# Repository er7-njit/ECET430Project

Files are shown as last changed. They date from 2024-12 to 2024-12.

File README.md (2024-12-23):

# GPS Tracker Project
Eliyahu Richter and Ravyn John's ECET 430 Project

Our initial **Project Definition** is available [here](https://github.com/er7-njit/GPSTracker430/blob/main/Documentation/Initial%20Project%20Definition.pdf)

Our final **Project Definition** is available [here](https://github.com/er7-njit/GPSTracker430/blob/main/Documentation/Final%20Project%20Definition.pdf)

A summary of our **Component Decisions** is available [here](https://github.com/er7-njit/GPSTracker430/blob/main/Documentation/Design%20decision.pdf)

**Documentation** is available [here](https://github.com/er7-njit/GPSTracker430/blob/main/Documentation/Documentation.md)

The **Logbook** for the project's progress is [here](https://github.com/er7-njit/GPSTracker430/wiki/Logbook)

Our **Project Files** are [here](https://github.com/er7-njit/GPSTracker430/tree/main/PCB%20Design)

Most questions about our project can be answered by the [wiki](https://github.com/er7-njit/GPSTracker430/wiki)





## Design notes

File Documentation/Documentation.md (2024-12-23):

# User Documentation

**DISCLAIMER: The Pi Tracker is still in development, the steps outlined here are for setup in uses related to development ONLY. The Pi Tracker is not supported, or recommended for use in production environments**

### Table of Contents
1. Supported Hardware
2. Device Summary
3. Basic Setup and Operation
4. Troubleshooting steps

## Supported Hardware
**Microcontrollers**:
- Raspberry Pi Zero W\
\
**OS Support**:
- Pi OS Lite\
\
**GPS Support**:
- Adafruit Ultimate GPS\
\
**WWAN Module Support**:
- Sierra Wireless EM7455

## Device Summary
The Pi Tracker is a tracking device that utilizes an Adafruit GPS module and a Sierra EM7455 WWAN Module to wirelessly transmit its location to the cloud. Its base componentry is a Pi Zero W (Figure 1), Adafruit Ultimate GPS attached by USB (Figure 2), and Sierra EM7455 WWAN Interface (FIgure 3) attached via a miniPCIe to USB adapter. Both of these interfaces are attached to a USB hub, which is connected to the Pi. 

## Basic Setup and Operation
**Device Assembly**
###
Firstly, connect the GPS and WWAN Module to the USB Hub. Then, connect the USB hub to the inner USB OTG port of the Pi Zero. Finally, connect the Pi to USB power using the outside USB port. 
###
**Device Setup**
###
1. Using the [Raspberry Pi Imager](https://www.raspberrypi.com/software/), flash Pi OS Lite onto an SD Card with a recommended size of 16GB or greater. Ensure that SSH and Wi-Fi settings are configured such that you can access the Pi via SSH.
2. Ensure the the Pi's software is fully up to date with the commands:\
   \
   `sudo apt update && sudo apt upgrade -y`
3. Ensure that nmcli, python3 and pip are installed with the commands:\
   \
   `sudo apt install python3 pip nmcli`
4. Configure APN Settings for SIM Card using nmcli:\
   ```
   sudo nmcli c add type gsm ifname <interface> con-name <name> apn <operator_apn>
   sudo nmcli connection up id <name>
   ```
   _Change <interface> to the corresponding interface name for your wwan module, as per ip link_\
   _Change <name> to your desired name for the connection, and <operator_apn> to your operator's APN_
6. The script requires several dependencies, install them within a python environment as root
   \
   `pip install board pytz adafruit-circuitpython-gps`
7. Clone this repository to an accesible folder in the home directory
8. cd to the scripts folder
9. Edit the script emailgps.py with your editor of choice
10. Change the variable `EMAIL_SENDER` to your email of choice
11. Run the script
12. Wait for fix and recieve the coordinates of the Pi Tracker at the chosen email and printed in the terminal
\
## Troubleshooting Steps
## Issues with Network
**Unable to Connect to Cellular Network**
- Ensure that the card is fully connected to the adapters and Pi
- Ensure the APN settings are configured using nmcli
- Ensure you are in an area of good cellular range

**Unable to Communicate with Pi via SSH**
- Ensure the Pi is connected to your LAN via the use of an IP Scanner or accessing your router's client list. Alternatively, you can plug in a monitor and peripherals and run iwconfig and a ping test.
- Ensure SSH is enabled on the Pi when flashing the image or using peripherals and a display. Alternatively, SSH can be enabled directly on the SD card. More information about this available [here](https://roboticsbackend.com/enable-ssh-on-raspberry-pi-raspbian/)

## Issues with GPS
**Unable to gain GPS Fix**
- Ensure the GPS has solid physical connection to the Pi, and that the Rx and Tx lights are illuminated and flashing, indicating data transmission and reception.
- Ensure the GPS is in a location that would have good GPS reception.

### Referenced Material
Screenshot From 2024-12-22 21-57-38
### **Figure 1**
###

### **Figure 2**
###

### **Figure 3**
###

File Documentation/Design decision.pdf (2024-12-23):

Eliyahu Richter | 12/22/24

All design decisions made during our project, sequentially.

### 1. Microcontroller

Our choice of micro controller was one of the most important decisions to the way the rest of the components were chosen. There were many factors to consider, mostly under the umbrella of software and hardware. Ultimately, our choice came down to two options, the Arduino Uno/Nano with the ATMEGA3P, and the Pi Zero W (for the form factor). Given considerations of difficulty of hardware configuration, as well as the fact that we had access to a Pi Zero W and GSM/GPRS hat already, we chose the Pi Zero W.

### 2. GSM/GPRS Hat

This was a choice that seemed easy, given the fact that we already had access to a SIMCOM R800C in a hat form factor for the Pi Zero, but ultimately configuration of the SIMCOM
R800C, both in hat and USB form factor proved too difficult for reasons outlined in the Project Logbook. Given our failure to successfully configure it for the prototype, we switched gears and used the Sierra Wireless EM7455 WWAN interface connected to two adapter boards, one to adapt M.2 to miniPCIe and one to adapt miniPCIe to USB.

### 3. GPS Module

Our choice for GPS module was based on ease of use, as we wanted to implement the task of pulling coordinates in a Python script, so a GPS with a well documented library would be nice. Our choice came down to the SAM-M8Q which the professor graciously offered us, and the Adafruit Ultimate GPS, which was available at our local Micro Center. We decided to try and play both sides, in the hopes of coming out on top. We ultimately ended up using the Adafruit GPS for its vast Python library, allowing us to directly integrate core functions into an easy to use Python script.

### 4. Software choices

There aren’t many software choices in our project, so I’m going to summarize them here. We chose Python as the language for our script because of familiarity, primarily, and pre-existing libraries. For a network management software for the WWAN interface, we chose NetworkManager, rather than ModemManager or configuring the device through AT commands because that is what worked. Every other method proved too convoluted or ineffective. Finally, the use of a remote software to log the location of the device devolved from using Nextcloud Phonetrack hosted remotely, to using an automated email as a proof of concept.

### 5. Battery choices

We wanted to integrate some type of battery in the device, just as a proof on concept, however we were unable to do so due to time constraints.

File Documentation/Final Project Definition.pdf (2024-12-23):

ECET 430 – Tracker Project Template

# Tracker Tag Project

Client:

John Smith, lead asset manager from Orange Trucking Company.

Budget: The prototype costed ~$74 to produce, but a single board device could

significantly reduce the cost.

Communication:

All source code and PCB schematics will be held on a GitHub repository,

alongside documentation written to help Orange’s in house techs diagnose and

manage devices. Technical support will be offered in a ticket-by-ticket form.

Objectives:

A low amperage, standalone tracking device that can integrate into the existing

12V system on a dry van trailer to offer reliable tracking information in case of

theft or other scenario of loss.

User Interaction

Ideally, user interaction will be minimal, apart from installation and configuration.

The tracker should be easily installed behind the header board, with easy access to the 7 way cable for simple electrical hookup. Configuration should be

possible remotely, once the device is assigned to an account. Configuration and

location logging should be done via a simple webGUI. Trouble codes should all

be available on the webGUI. In case of loss of connection, time offline should

trigger an alert and log how long each device has been offline. Finally, the

device should ideally never require servicing, and in case of required firmware

updates, they should all be possible remotely. In case of a damaged device,

schematics and troubleshooting procedures will be available on the repository,

as well as a manufacturer offered repair service. These objectives will take more

software optimizations, such as an integration of the API of Nextcloud

Phonetrack into the GPS software to allow communication between the Pi and

remote server.

Interface

The device will be remotely accessible via SSH, over the cellular network it uses

for tracking.

Parameters

ECET 430 – Tracker Project Template

The device should fit in a 3”x5” rectangular space, and weigh less than 5

pounds. It will be rated IPX8 or higher for permanent exterior use, and be water,

shock, and dust proof. The ratings will be with the device equipped in a case.

Functions

The device will offer accurate, up to 50m, location logging for van trailers, with

the goal being to offer an effective tool to a company managing tens of

thousands of units.

Integration

The device will utilize IOT LTE, 3G, and 2G networks to avoid a monthly cost per

device while maintaining reliable tracking information.

Operational

The device’s runtime will be restricted by how long a unit remains disconnected

from an electrical system. The goal will be to have the tracker run independently

for several months before requiring a charge, however the device will charge

every time the unit is moved. This optimization should be done with the device’s

particular application chosen, and voltage source chosen to fit the application.

Life Cycle

The device will be easy and quick to produce, ideally built from easily sourced

components for easy manufacturing and repair. Given that it is a tracker that will

be installed in tens of thousands of units, long term support is a must. The goal

will be to support these devices for a minimum of 15 years, with extended

support available.

Environments

This device will be stored on the interior of a van trailer, but must be rated for

constant exterior use. Temperatures will vary from 115 degrees F to -20 degrees

F, as these units travel all over the North American continent.

Starting Point

This device offers similar functionality to other, vehicle specific, trackers, as well

as the Apple Airtag. While the goal is to build a unique device with its own

recognizable capability, the similarities must be acknowledged. The device will

utilize open source tracking software and GSM/GPRS drivers.

Key Concerns

ECET 430 – Tracker Project Template

The device must be able to continue tracking without power for a certain amount

of time, otherwise the usefulness of the tracker will be limited. Additionally, the

device must be installed in such a way that it is not easily tampered with, and

notifies an admin if it is being tampered with.

Conclusions

For a successful deployment, the device will need more development,

specifically in the areas of having the GPS location reliably be obtained, and

transmitted to the cloud. Furthermore, to have the device actually function,

testing should be done to determine voltage and amperage ratings, and

recommended pairings with voltage sources in several different scenarios. In

terms of hardware, integrating all the components onto a single board could

significantly decrease both footprint and price (depending on producer), which is

important in several weather and space sensitive deployments, leading to the

final consideration, a case. The case should be accessible as a part of the

project files, and be able to endure impact and adverse weather conditions. As it

stands now, to implement this device would require significant work which would

dwarf the price of reverting to another commercial solution, and a core goal of

this project is to compete with those same commercial solutions. While the

tracker needs more development, it can do so publicly as the designs and software are all open source. Once the product reaches maturity, I believe it will

be able to compete with those solutions, and be able to do it better than if it was

closed source and proprietary.

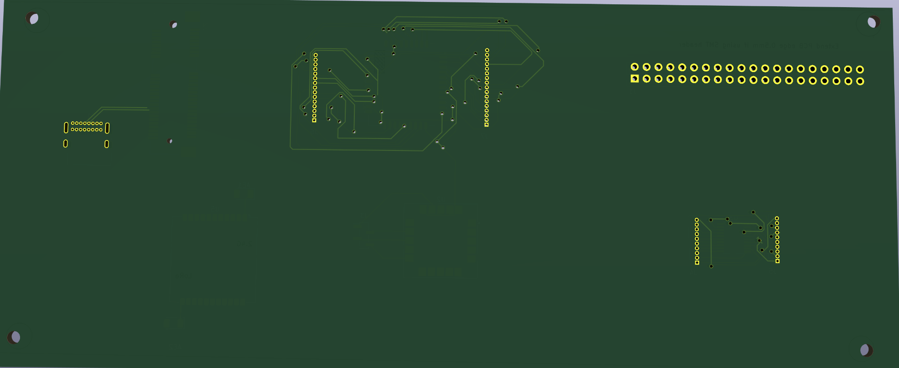
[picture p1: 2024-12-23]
PCB Design Files with Gerber Files and Board Images/Back view of board.png

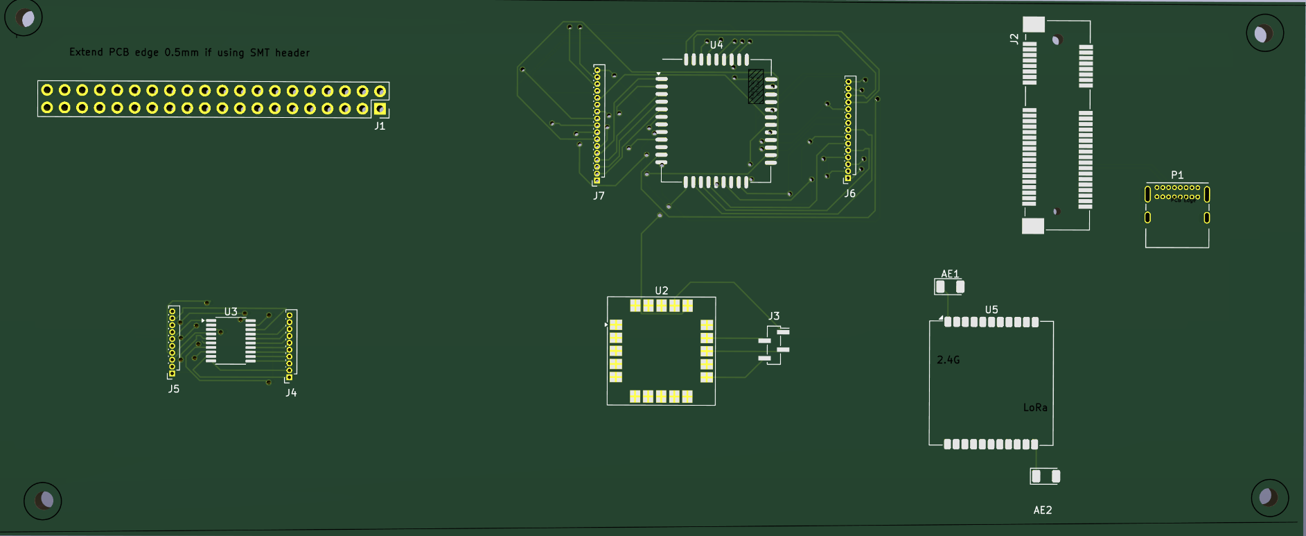
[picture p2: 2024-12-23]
PCB Design Files with Gerber Files and Board Images/Front View of Board.png

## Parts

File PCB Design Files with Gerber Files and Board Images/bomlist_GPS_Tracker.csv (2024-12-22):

Reference | Value | Datasheet | Footprint | Qty | DNP
AE1,AE2 | Antenna | ~ | RF_Antenna:Johanson_2450AT18x100 | 2
C1 | 100n | ~ |  | 1
J1 | GPIO |  | Connector_PinSocket_2.54mm:PinSocket_2x20_P2.54mm_Vertical | 1
J2 | Bus_PCI_Express_Mini | ~ | Connector_PCBEdge:BUS_PCI_Express_Mini | 1
J3 | Conn_01x04_Socket | ~ | Connector_PinSocket_1.27mm:PinSocket_1x04_P1.27mm_Vertical_SMD_Pin1Right | 1
J4,J5 | Conn_01x10_Socket | ~ | -- mixed values -- | 2
J6 | Conn_01x15_Socket | ~ | Connector_PinSocket_1.27mm:PinSocket_1x15_P1.27mm_Vertical_SMD_Pin1Left | 1
J7 | Conn_01x17_Socket | ~ | Connector_PinSocket_1.27mm:PinSocket_1x17_P1.27mm_Vertical_SMD_Pin1Left | 1
JP1 | ID_WP | ~ |  | 1
P1 | USB_C_Plug_USB2.0 | https://www.usb.org/sites/default/files/documents/usb_type-c.zip | Connector_USB:USB_C_Plug_Molex_105444 | 1
R1,R2 | 3.9k | ~ |  | 2
U1 | CAT24C256 | https://www.onsemi.cn/PowerSolutions/document/CAT24C256-D.PDF |  | 1
U2 | SAM-M8Q | https://www.u-blox.com/sites/default/files/SAM-M8Q_DataSheet_%28UBX-16012619%29.pdf | RF_GPS:ublox_SAM-M8Q | 1
U3 | CH32V003FxPx | https://www.wch-ic.com/products/CH32V003.html | Package_SO:TSSOP-20_4.4x6.5mm_P0.65mm | 1
U4 | SIM800C | http://simcom.ee/documents/SIM800C/SIM800C_Hardware_Design_V1.05.pdf | RF_GSM:SIMCom_SIM800C | 1
U5 | HT-CT62 | https://resource.heltec.cn/download/HT-CT62/HT-CT62(Rev1.1).pdf | RF_Module:Heltec_HT-CT62 | 1

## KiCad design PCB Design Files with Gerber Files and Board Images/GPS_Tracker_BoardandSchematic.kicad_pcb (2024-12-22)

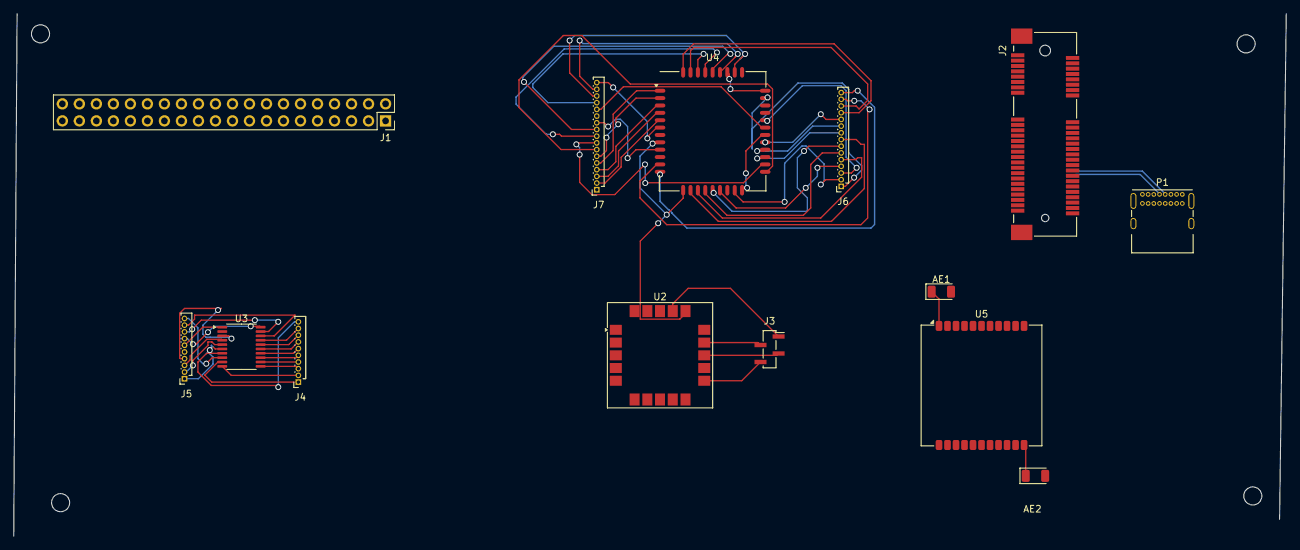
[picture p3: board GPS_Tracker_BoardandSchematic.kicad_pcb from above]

Board: 2 copper layers, 190.0 x 78.0 mm, 18 parts (0 on the bottom side), 60 nets.

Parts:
AE1, AE2: Antenna; Johanson_2450AT18x100
J1: GPIO; PinSocket_2x20_P2.54mm_Vertical
J2: Bus_PCI_Express_Mini; BUS_PCI_Express_Mini
J3: Conn_01x04_Socket; PinSocket_1x04_P1.27mm_Vertical_SMD_Pin1Right
J4, J5: Conn_01x10_Socket; PinSocket_1x10_P1.00mm_Vertical
J6: Conn_01x15_Socket; PinSocket_1x15_P1.00mm_Vertical
J7: Conn_01x17_Socket; PinSocket_1x17_P1.00mm_Vertical
MH1, MH2, MH3, MH4: MountingHole_2.7mm_M2.5
P1: USB_C_Plug_USB2.0; USB_C_Receptacle_GCT_USB4085
U2: SAM-M8Q; ublox_SAM-M8Q
U3: CH32V003FxPx; TSSOP-20_4.4x6.5mm_P0.65mm
U4: SIM800C; SIMCom_SIM800C
U5: HT-CT62; Heltec_HT-CT62

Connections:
+3V3: J1.1, J1.17
+5V: J1.2, J1.4
GND: J1.6, J1.9, J1.14, J1.20, J1.25, J1.30, J1.34, J1.39, J3.4, J7.16, U2.1 (GND), U2.4 (GND), U2.5 (GND), U2.6 (GND), U2.10 (GND), U2.11 (GND), U2.15 (GND), U2.16 (GND), U2.20 (GND), U4.8 (GND), U4.13 (GND), U4.19 (GND), U4.21 (GND), U4.27 (GND), U4.30 (GND), U4.31 (GND), U4.33 (GND), U4.36 (GND), U4.37 (GND)
unnamed: AE1.1 (A), U5.1 (2.4G_Ant)
unnamed: AE2.1 (A), U5.22 (LoRa_Ant)
unnamed: J2.38 (USB_D+), P1.A6 (D+)
unnamed: J2.36 (USB_D-), P1.A7 (D-)
unnamed: J3.1, U2.17 (VCC)
unnamed: J3.2, U2.14 (RXD)
unnamed: J3.3, U2.13 (TXD)
unnamed: J4.1, U3.9 (VDD)
unnamed: J4.2, U3.10 (PC0)
unnamed: J4.3, U3.11 (PC1)
unnamed: J4.4, U3.12 (PC2)
unnamed: J4.5, U3.13 (PC3)
unnamed: J4.6, U3.14 (PC4)
unnamed: J4.7, U3.15 (PC5)
unnamed: J4.8, U3.16 (PC6)
unnamed: J4.9, U3.17 (PC7)
unnamed: J4.10, U3.7 (VSS)
unnamed: J5.1, U3.6 (PA2)
unnamed: J5.2, U3.5 (PA1)
unnamed: J5.3, U3.4 (PD7)
unnamed: J5.4, U3.3 (PD6)
unnamed: J5.6, U3.1 (PD4)
unnamed: J5.7, U3.20 (PD3)
unnamed: J5.8, U3.19 (PD2)
unnamed: J5.9, U3.18 (PD1)
unnamed: J5.10, U3.8 (PD0)
unnamed: J6.1, U4.32 (GSM_ANT)
unnamed: J6.2, U4.20 (BT_ANT)
unnamed: J6.3, U4.29 (RF_SYNC)
unnamed: J6.4, U4.18 (SIM_VDD)
unnamed: J6.5, U4.15 (SIM_DATA)
unnamed: J6.6, U4.16 (SIM_CLK)
unnamed: J6.7, U4.17 (SIM_RST)
unnamed: J6.8, U4.14 (SIM_DET)
unnamed: J6.9, U4.24 (USB_VBUS)
unnamed: J6.10, U4.25 (USB_DP)
unnamed: J6.11, U4.26 (USB_DM)
unnamed: J6.12, U4.42 (STATUS)
unnamed: J6.13, U4.41 (NETLIGHT)
unnamed: J6.14, U4.11 (SPKP)
unnamed: J6.15, U4.12 (SPKN)
unnamed: J7.1, U4.7 (UART1_RI)
unnamed: J7.2, U4.5 (UART1_DCD)
unnamed: J7.3, U4.4 (UART1_CTS)
unnamed: J7.4, U4.3 (UART1_RTS)
unnamed: J7.5, U4.1 (UART1_TXD)
unnamed: J7.6, U4.2 (UART1_RXD)
unnamed: J7.7, U4.22 (UART2_TXD)
unnamed: J7.8, U4.23 (UART2_RXD)
unnamed: J7.9, U4.39 (~PWRKEY)
unnamed: J7.10, U4.38 (ADC)
unnamed: J7.11, U4.9 (MICP)
unnamed: J7.12, U4.10 (MICN)
unnamed: J7.13, U4.28 (VRTC)
unnamed: J7.14, U4.40 (VDD_EXT)
unnamed: J7.15, U4.34 (VBAT), U4.35 (VBAT)
unnamed: J7.17, U4.6 (UART1_DTR)

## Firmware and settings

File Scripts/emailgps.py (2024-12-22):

import time
from datetime import datetime
import pytz
import board
import busio
import adafruit_gps
import smtplib
import ssl
from email.mime.text import MIMEText
from email.mime.multipart import MIMEMultipart
import serial

# Serial connection for GPS module
uart = serial.Serial("/dev/ttyUSB0", baudrate=9600, timeout=10)

# Create a GPS module instance
gps = adafruit_gps.GPS(uart, debug=False)

# GPS initialization commands
gps.send_command(b"PMTK314,0,1,0,1,0,0,0,0,0,0,0,0,0,0,0,0,0,0,0")
gps.send_command(b"PMTK220,1000")

# Timezone setup
eastern = pytz.timezone('US/Eastern')

# Email configuration
EMAIL_SENDER = "rj65@njit.edu"
EMAIL_PASSWORD = "tdqq jdqy plop avdu"
EMAIL_RECEIVER = "rj65@njit.edu"
SMTP_SERVER = "smtp.gmail.com"
SMTP_PORT = 465

# Function to send an email with GPS data
def send_email(latitude, longitude, timestamp, speed_kmh=None):
    # Create the email content
    message = MIMEMultipart()
    message["From"] = EMAIL_SENDER
    message["To"] = EMAIL_RECEIVER
    message["Subject"] = "GPS Location Fix"

    # Email body
    email_content = f"""
    GPS Location Fix:
    Timestamp (Eastern Time): {timestamp}
    Latitude: {latitude:.6f} degrees
    Longitude: {longitude:.6f} degrees
    Speed: {speed_kmh if speed_kmh else 'N/A'} km/h
    """
    message.attach(MIMEText(email_content, "plain"))

    # Secure SSL context
    context = ssl.create_default_context()

    # Sending the email
    with smtplib.SMTP_SSL(SMTP_SERVER, SMTP_PORT, context=context) as server:
        server.login(EMAIL_SENDER, EMAIL_PASSWORD)
        server.sendmail(EMAIL_SENDER, EMAIL_RECEIVER, message.as_string())

    print("Email sent successfully!")

# Main loop
last_print = time.monotonic()
email_sent = False

while True:
    gps.update()
    current = time.monotonic()

    if current - last_print >= 1.0:
        last_print = current
        if not gps.has_fix:
            print("Waiting for fix...")
            continue

        # Get UTC time and convert it to Eastern Time
        utc_time = gps.timestamp_utc
        if utc_time is not None:
            utc_datetime = datetime(utc_time.tm_year, utc_time.tm_mon, utc_time.tm_mday,
                                    utc_time.tm_hour, utc_time.tm_min, utc_time.tm_sec, tzinfo=pytz.UTC)
            eastern_time = utc_datetime.astimezone(eastern)
            formatted_time = eastern_time.strftime("%m/%d/%Y %I:%M:%S %p")

            # Print GPS information
            print("=" * 40)
            print(f"Timestamp (Eastern Time): {formatted_time}")
            print(f"Latitude: {gps.latitude:.6f} degrees")
            print(f"Longitude: {gps.longitude:.6f} degrees")
            if gps.speed_kmh is not None:
                print(f"Speed: {gps.speed_kmh} km/h")

            # Send email only once when we get the first fix
            if not email_sent:
                send_email(gps.latitude, gps.longitude, formatted_time, gps.speed_kmh)
                email_sent = True  # Prevent multiple emails

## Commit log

2024-12-22 Create BOM
    find the bom list here
2024-12-22 Renamed to older version
    [GPSTracker_Design_10-8-24.kicad_sch]
